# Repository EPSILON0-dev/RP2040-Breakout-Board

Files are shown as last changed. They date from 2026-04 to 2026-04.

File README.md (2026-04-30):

# RP2040 Breakout Board

Minimal RP2040 breakout with USB Micro-B, 16 MB QSPI flash, and full GPIO headers in a breadboard-friendly form factor.

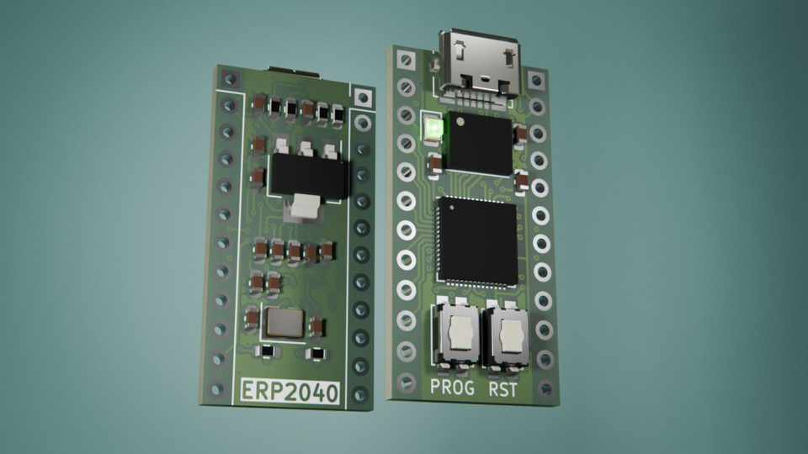
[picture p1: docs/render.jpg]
Board Render


---

## Pin Reference

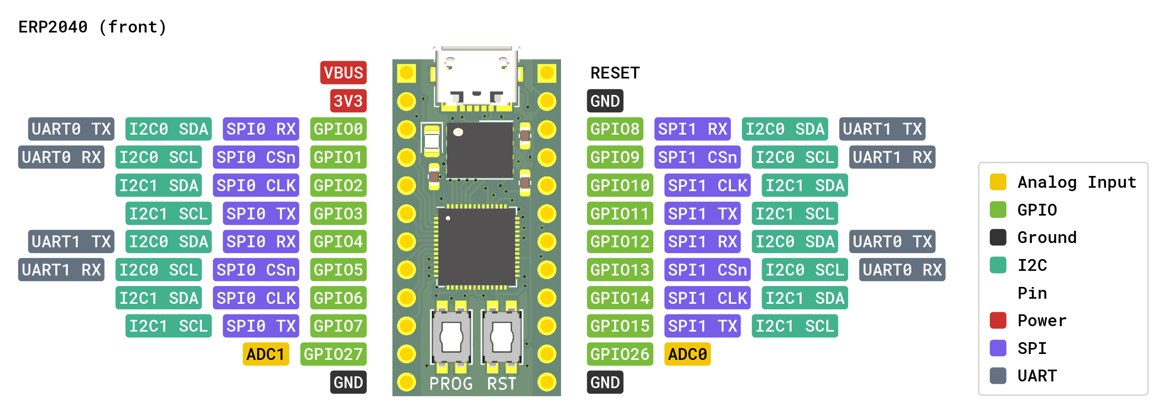
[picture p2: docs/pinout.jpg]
Board Pinout


---

## Specifications

| Parameter | Value |
|---|---|
| MCU | RP2040 (dual-core Arm Cortex-M0+ @ up to 133 MHz) |
| Flash | 16 MB W25Q128JVS (QSPI) or compatible |
| Supply voltage | 5 V via USB Micro-B; 3.3 V via onboard AP1117-33 LDO |
| Internal 1.1 V rail | Generated by RP2040 internal LDO (VREG) |
| Clock | 12 MHz external crystal |
| USB | USB Micro-B (power + data) |
| GPIO headers | 2 × 12-pin 2.54 mm (J2, J3) |
| Status | Tested - fully functional |

---

## Schematic and PCB

| Schematic | Board |
|:---:|:---:|
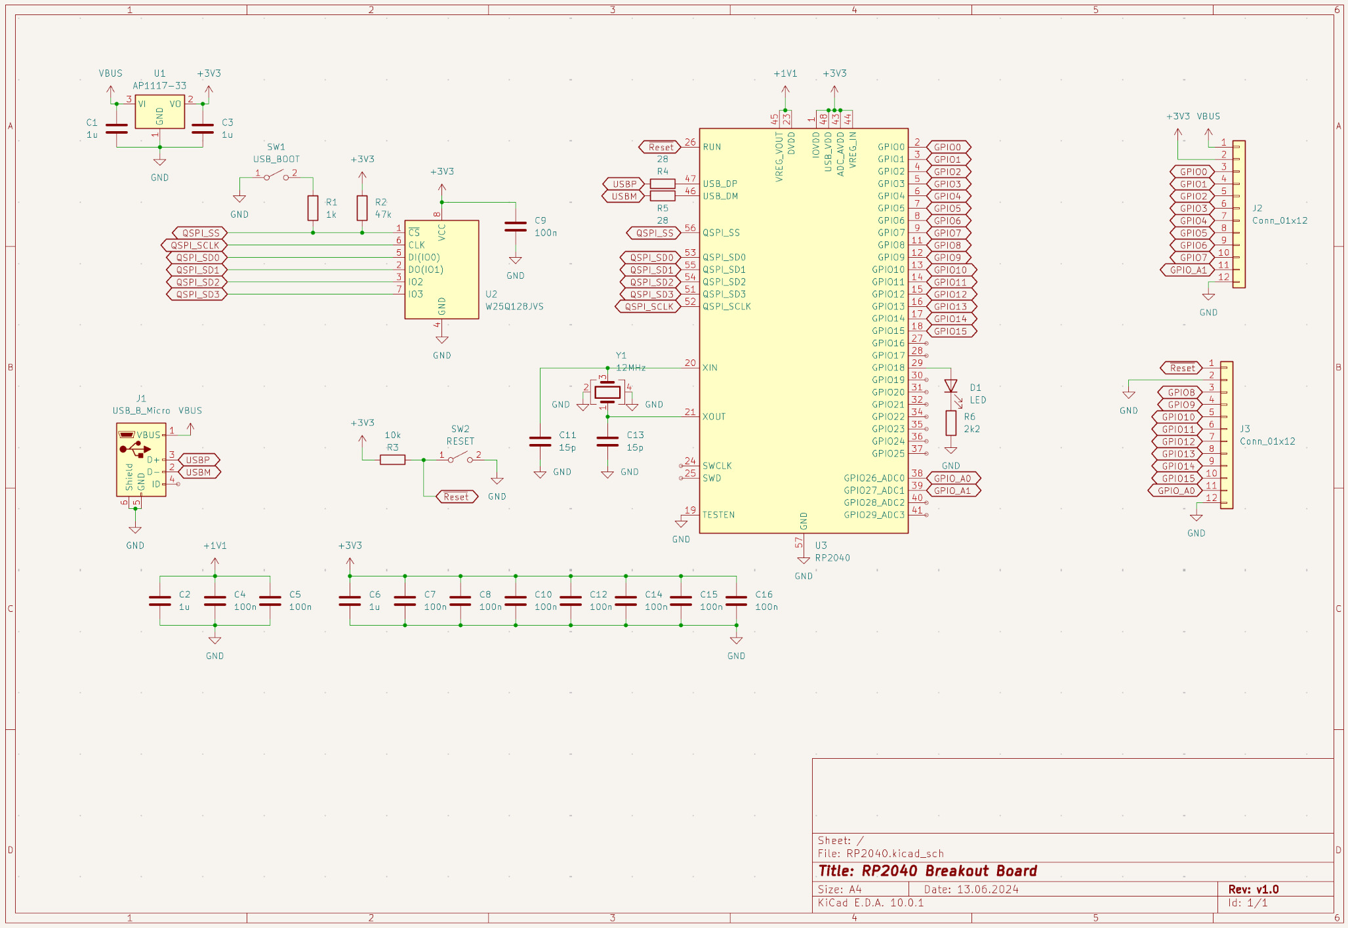
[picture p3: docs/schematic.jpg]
Schematic
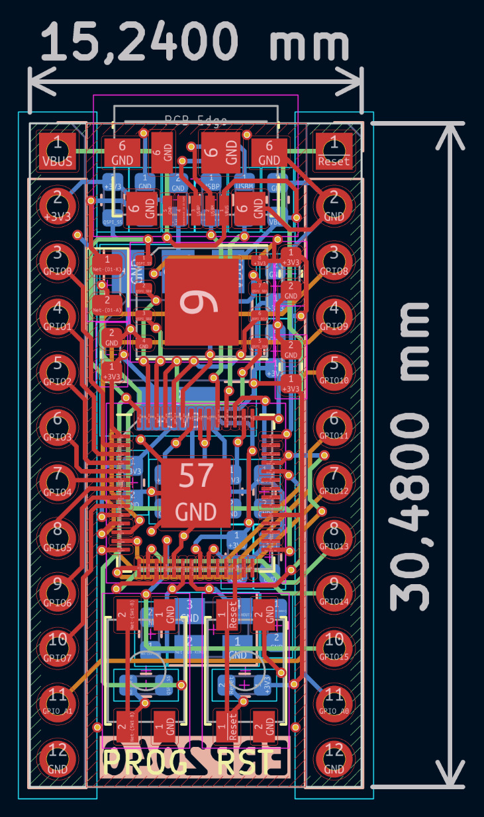
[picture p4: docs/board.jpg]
Board
|  |  |

---

## Boot & Reset

| Control | Component | Behaviour |
|---|---|---|
| **BOOT** | SW1 (USB_BOOT) | Hold while connecting USB to enter USB bootloader (UF2 mode). Pulls QSPI_SS low via R1 (1 kΩ); R2 (47 kΩ) pulls QSPI_SS high normally. |
| **RESET** | SW2 (RESET) | Momentarily pulls RUN low. R3 (10 kΩ) holds RUN high during normal operation. |

---

## Manufacturing

Gerber files are in the [`gerber/`](gerber/) directory, ready to upload to JLCPCB, PCBWay, or equivalent.

Suggested fab settings:

| Setting | Value |
|---|---|
| Layers | 4 (F_Cu, In1_Cu, In2_Cu, B_Cu) |
| Thickness | 1.6 mm |
| Surface finish | HASL (lead-free) or ENIG |

---

## Status

- [x] Designed, not yet ordered
- [x] Ordered — awaiting boards
- [x] Assembled, untested
- [x] Tested and working

---

## Building / Programming

### USB Bootloader (UF2)

```bash
# 1. Hold SW1 (BOOT button) and connect USB — board appears as RPI-RP2 mass storage
# 2. Drag and drop a UF2 firmware image
cp firmware.uf2 /media/$USER/RPI-RP2
```

---

## License

Licensed under the MIT [License](LICENSE)

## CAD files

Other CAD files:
docs/model.blend

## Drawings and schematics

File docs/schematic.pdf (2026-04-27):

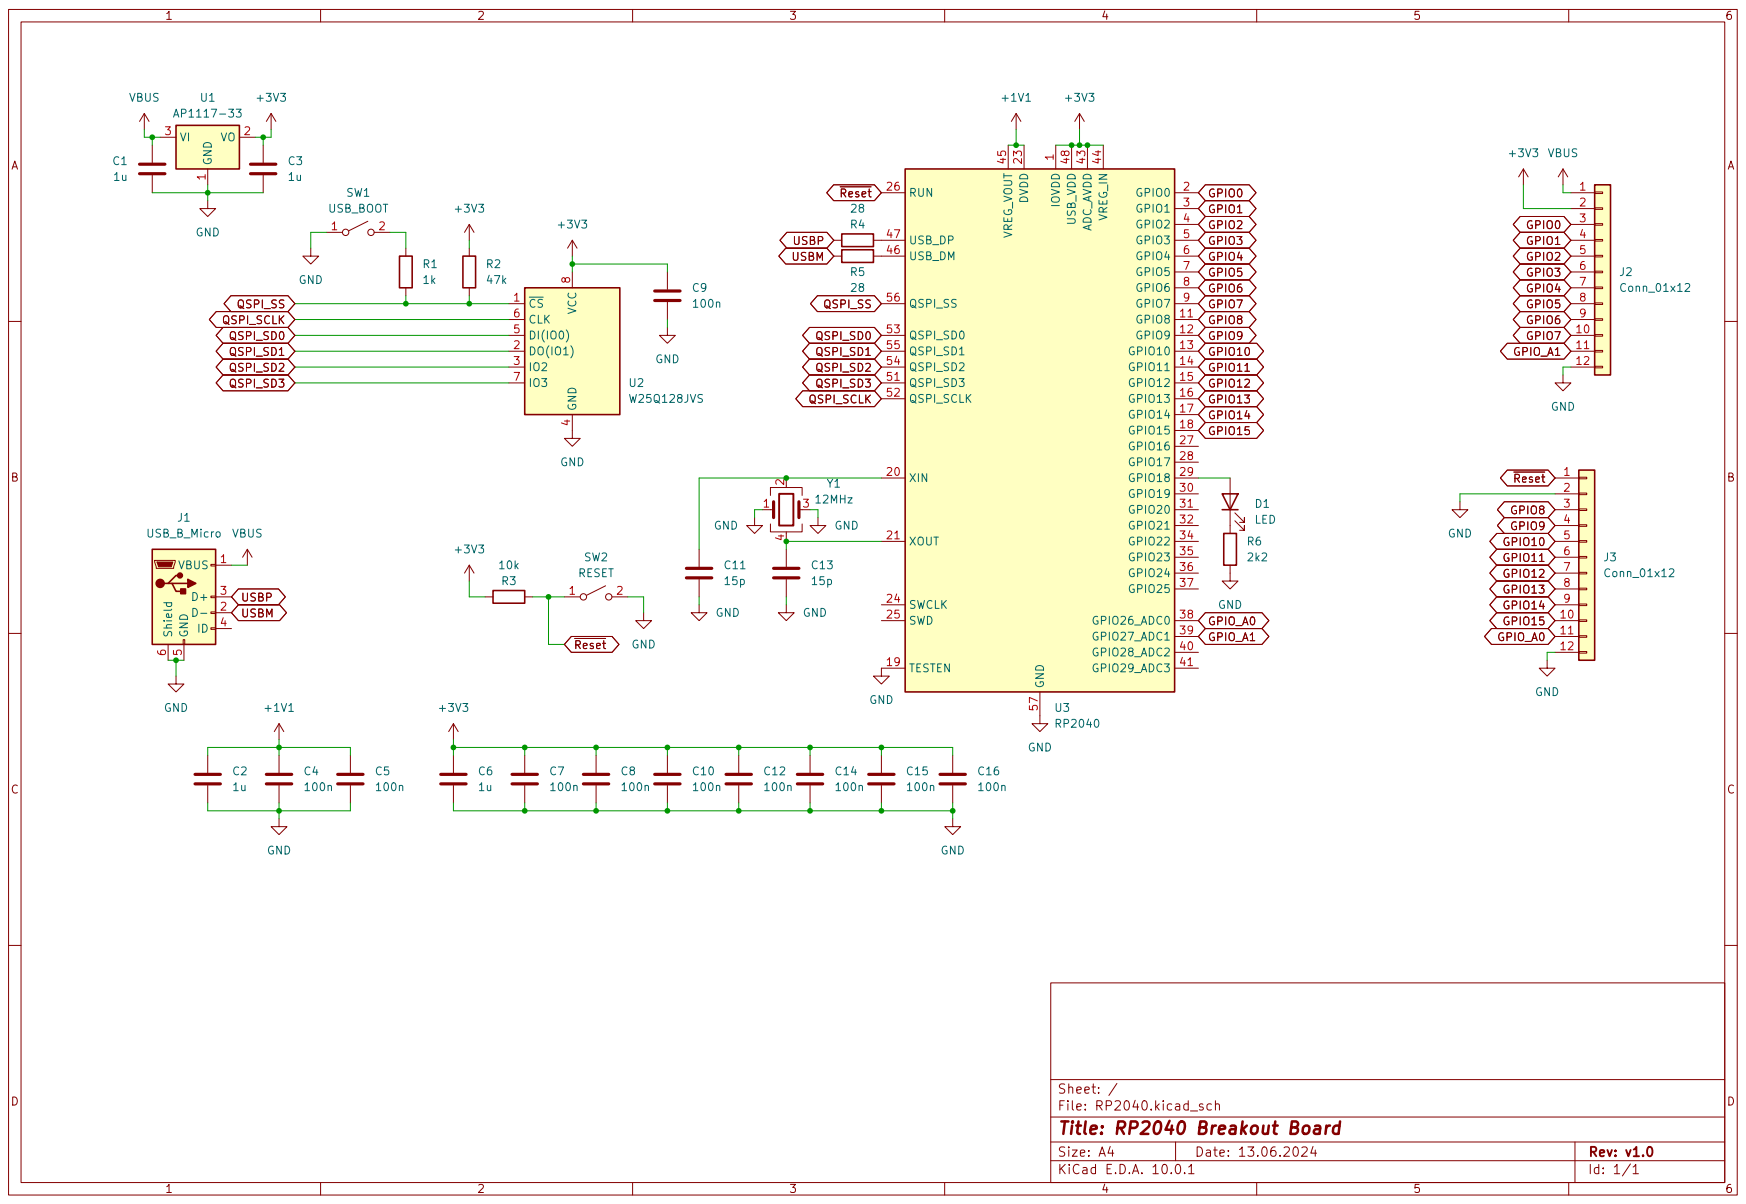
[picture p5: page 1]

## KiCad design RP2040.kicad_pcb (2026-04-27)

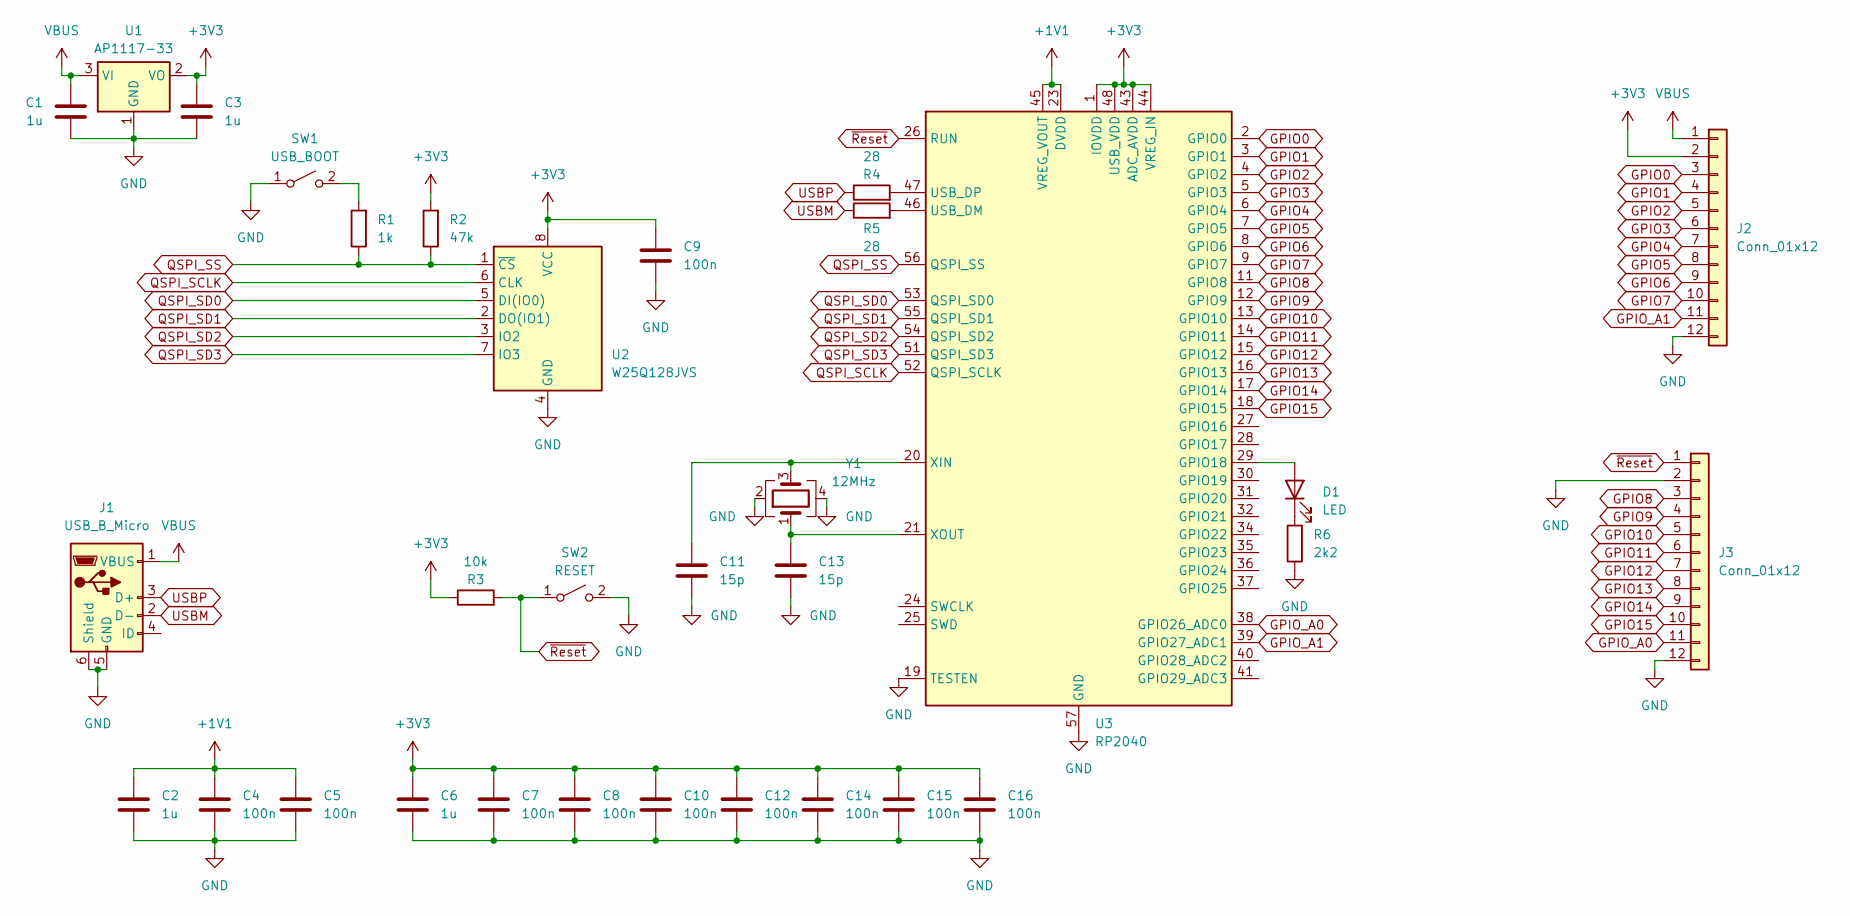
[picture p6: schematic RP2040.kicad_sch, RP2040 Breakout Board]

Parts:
C1, C2, C3, C6: 1u; C_0603_1608Metric
C4, C5, C7, C8, C9, C10, C12, C14, C15, C16: 100n; C_0603_1608Metric
C11, C13: 15p; C_0603_1608Metric
D1: LED; LED_0805_2012Metric
J1: USB_B_Micro; USB_Micro-B_Molex_47346-0001
J2, J3: Conn_01x12; PinHeader_1x12_P2.54mm_Vertical
R1: 1k; R_0603_1608Metric
R2: 47k; R_0603_1608Metric
R3: 10k; R_0603_1608Metric
R4, R5: 28; R_0603_1608Metric
R6: 2k2; R_0603_1608Metric
SW1: USB_BOOT; SW_SPST_EVQP2
SW2: RESET; SW_SPST_EVQP2
U1: AP1117-33; SOT-223-3_TabPin2
U2: W25Q128JVS; WSON-8-1EP_6x5mm_P1.27mm_EP3.4x4mm
U3: RP2040; QFN-56-1EP_7x7mm_P0.4mm_EP3.2x3.2mm
Y1: 12MHz; Crystal_SMD_3225-4Pin_3.2x2.5mm

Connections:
+1V1: C2.1, C4.1, C5.1, U3.23 (DVDD), U3.45 (VREG_VOUT), U3.50 (DVDD)
+3V3: C3.1, C6.1, C7.1, C8.1, C9.1, C10.1, C12.1, C14.1, C15.1, C16.1, J2.2, R2.2, R3.1, U1.2 (VO), U2.8 (VCC), U3.1 (IOVDD), U3.10 (IOVDD), U3.22 (IOVDD), U3.33 (IOVDD), U3.42 (IOVDD), U3.43 (ADC_AVDD), U3.44 (VREG_IN), U3.48 (USB_VDD), U3.49 (IOVDD)
GND: C1.2, C2.2, C3.2, C4.2, C5.2, C6.2, C7.2, C8.2, C9.2, C10.2, C11.2, C12.2, C13.2, C14.2, C15.2, C16.2, J1.5 (GND), J1.6 (Shield), J2.12, J3.2, J3.12, R6.1, SW1.1 (A), SW2.2 (B), U1.1 (GND), U2.4 (GND), U3.19 (TESTEN), U3.57 (GND), Y1.2, Y1.4
GPIO0: J2.3, U3.2 (GPIO0)
GPIO1: J2.4, U3.3 (GPIO1)
GPIO2: J2.5, U3.4 (GPIO2)
GPIO3: J2.6, U3.5 (GPIO3)
GPIO4: J2.7, U3.6 (GPIO4)
GPIO5: J2.8, U3.7 (GPIO5)
GPIO6: J2.9, U3.8 (GPIO6)
GPIO7: J2.10, U3.9 (GPIO7)
GPIO8: J3.3, U3.11 (GPIO8)
GPIO9: J3.4, U3.12 (GPIO9)
GPIO10: J3.5, U3.13 (GPIO10)
GPIO11: J3.6, U3.14 (GPIO11)
GPIO12: J3.7, U3.15 (GPIO12)
GPIO13: J3.8, U3.16 (GPIO13)
GPIO14: J3.9, U3.17 (GPIO14)
GPIO15: J3.10, U3.18 (GPIO15)
GPIO_A0: J3.11, U3.38 (GPIO26_ADC0)
GPIO_A1: J2.11, U3.39 (GPIO27_ADC1)
unnamed: D1.2 (A), U3.29 (GPIO18)
unnamed: D1.1 (K), R6.2
unnamed: R1.2, SW1.2 (B)
unnamed: R5.2, U3.46 (USB_DM)
unnamed: R4.2, U3.47 (USB_DP)
unnamed: C11.1, U3.20 (XIN), Y1.3
unnamed: C13.1, U3.21 (XOUT), Y1.1
QSPI_SCLK: U2.6 (CLK), U3.52 (QSPI_SCLK)
QSPI_SD0: U2.5 (DI(IO0)), U3.53 (QSPI_SD0)
QSPI_SD1: U2.2 (DO(IO1)), U3.55 (QSPI_SD1)
QSPI_SD2: U2.3 (IO2), U3.54 (QSPI_SD2)
QSPI_SD3: U2.7 (IO3), U3.51 (QSPI_SD3)
QSPI_SS: R1.1, R2.1, U2.1 (~CS), U3.56 (QSPI_SS)
USBM: J1.2 (D-), R5.1
USBP: J1.3 (D+), R4.1
VBUS: C1.1, J1.1 (VBUS), J2.1, U1.3 (VI)
~Reset: J3.1, R3.2, SW2.1 (A), U3.26 (RUN)

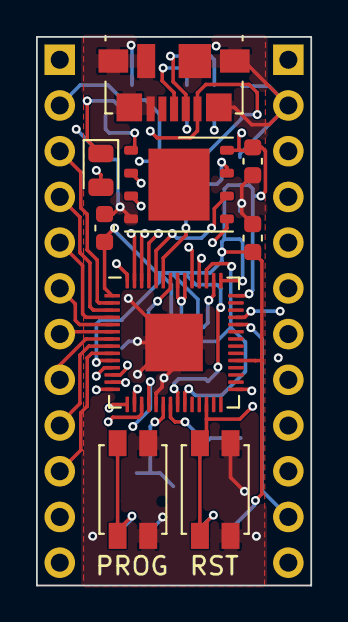
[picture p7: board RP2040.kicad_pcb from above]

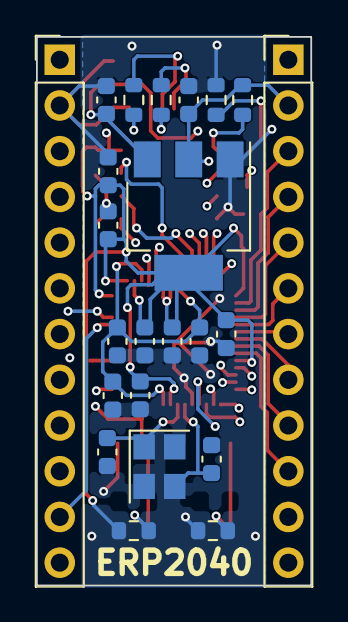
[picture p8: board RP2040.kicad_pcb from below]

Board: 4 copper layers, 15.2 x 30.5 mm, 32 parts (23 on the bottom side), 38 nets.

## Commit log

2026-04-27 init: Initial Commit
    [RP2040-B_Cu.gbl, RP2040-B_Mask.gbs, RP2040-B_Paste.gbp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]
2026-04-27 fix: Fix crystal orientation
    [RP2040.kicad_pcb, RP2040.kicad_sch]
2026-04-27 fix: fix schematic and redundant files
